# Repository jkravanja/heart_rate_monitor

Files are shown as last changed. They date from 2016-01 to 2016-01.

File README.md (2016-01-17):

# heart_rate_monitor
Heart rate monitor designed in KiCad, using Nordic Semiconductor NRF51822 bluetooth module and TI AFE4400 heart rate module.

The repository contains a KiCad design of a 5x5 cm heart rate monitor breakout board. Some libraries were borrowed from Guan Yang's github projects (https://github.com/guanix/boards). Also, some design aspects of the circuit were inspired by HackManhattan Nordic nrf51822 beakout board (http://dangerousprototypes.com/2013/05/19/hackmanhattans-nordic-nrf51822-breakout-board/)

[Schematics](https://github.com/jkravanja/heart_rate_monitor/blob/master/hr.pdf)

In addition to AFE440 for heart rate measurements and NRF51822 for BLE communications, the circuit also contains a [Freescale MMA8452 3-axis accelerometer](http://www.nxp.com/files/sensors/doc/data_sheet/MMA8452Q.pdf), CAT24M01 1Mb EEPROM and an additional heart rate circuit composed of just a few simple elements (see bottom center of the schematics). The circuit was inspired by [this article](http://www.biofotonika.lu.lv/fileadmin/user_upload/lu_portal/projekti/biofotonika/Publikacijas/A4/SPIE/22.Kviesis-A_photoplethysmography_device_for_multipurpose_bloo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) and presents a cheaper and simpler option to AFE4400.

Image of manufactured PCB

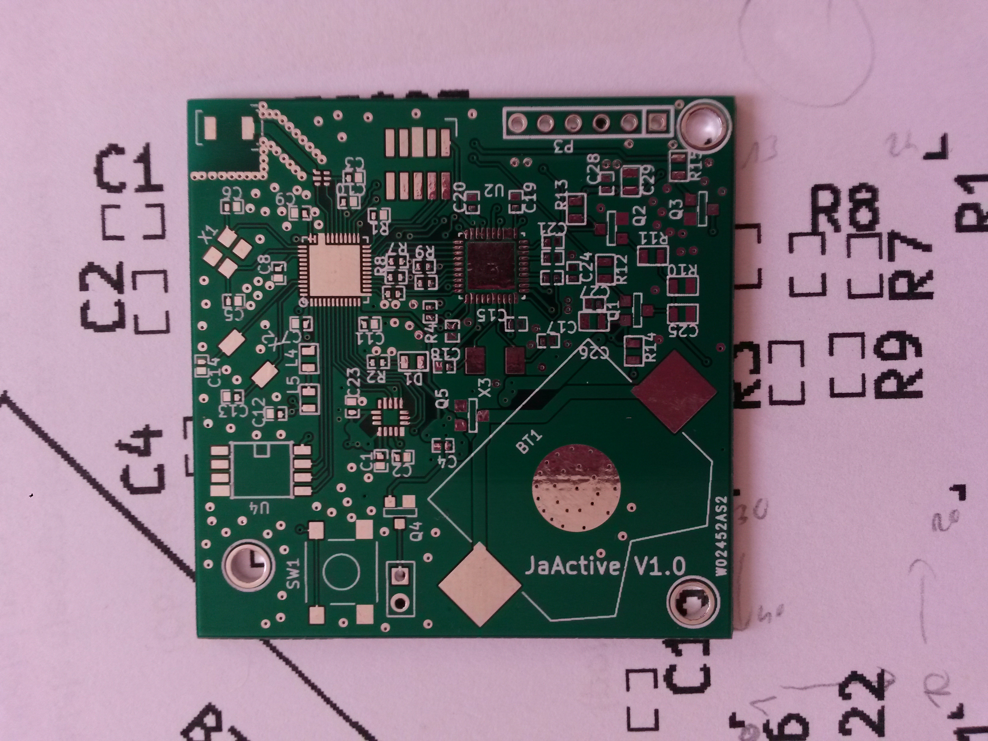
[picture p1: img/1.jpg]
Image of manufactured PCB


Components were soldered with reflow technique. Some joints had to be manually corrected using soldering iron

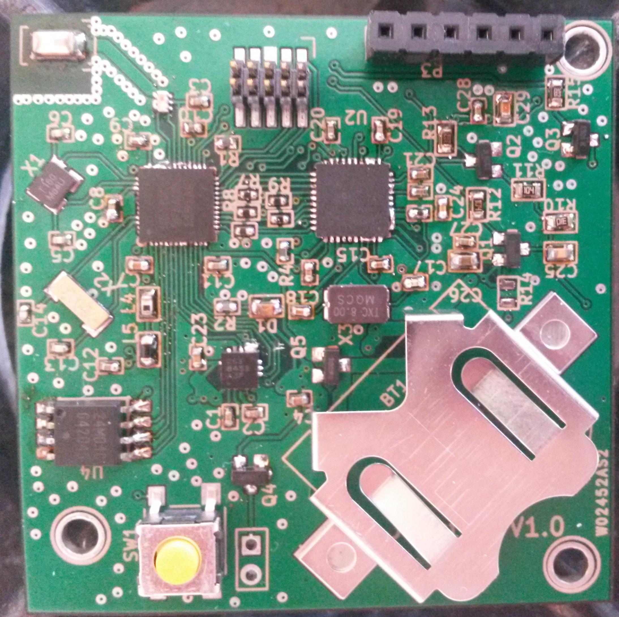
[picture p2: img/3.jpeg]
Added battery holder and connectors


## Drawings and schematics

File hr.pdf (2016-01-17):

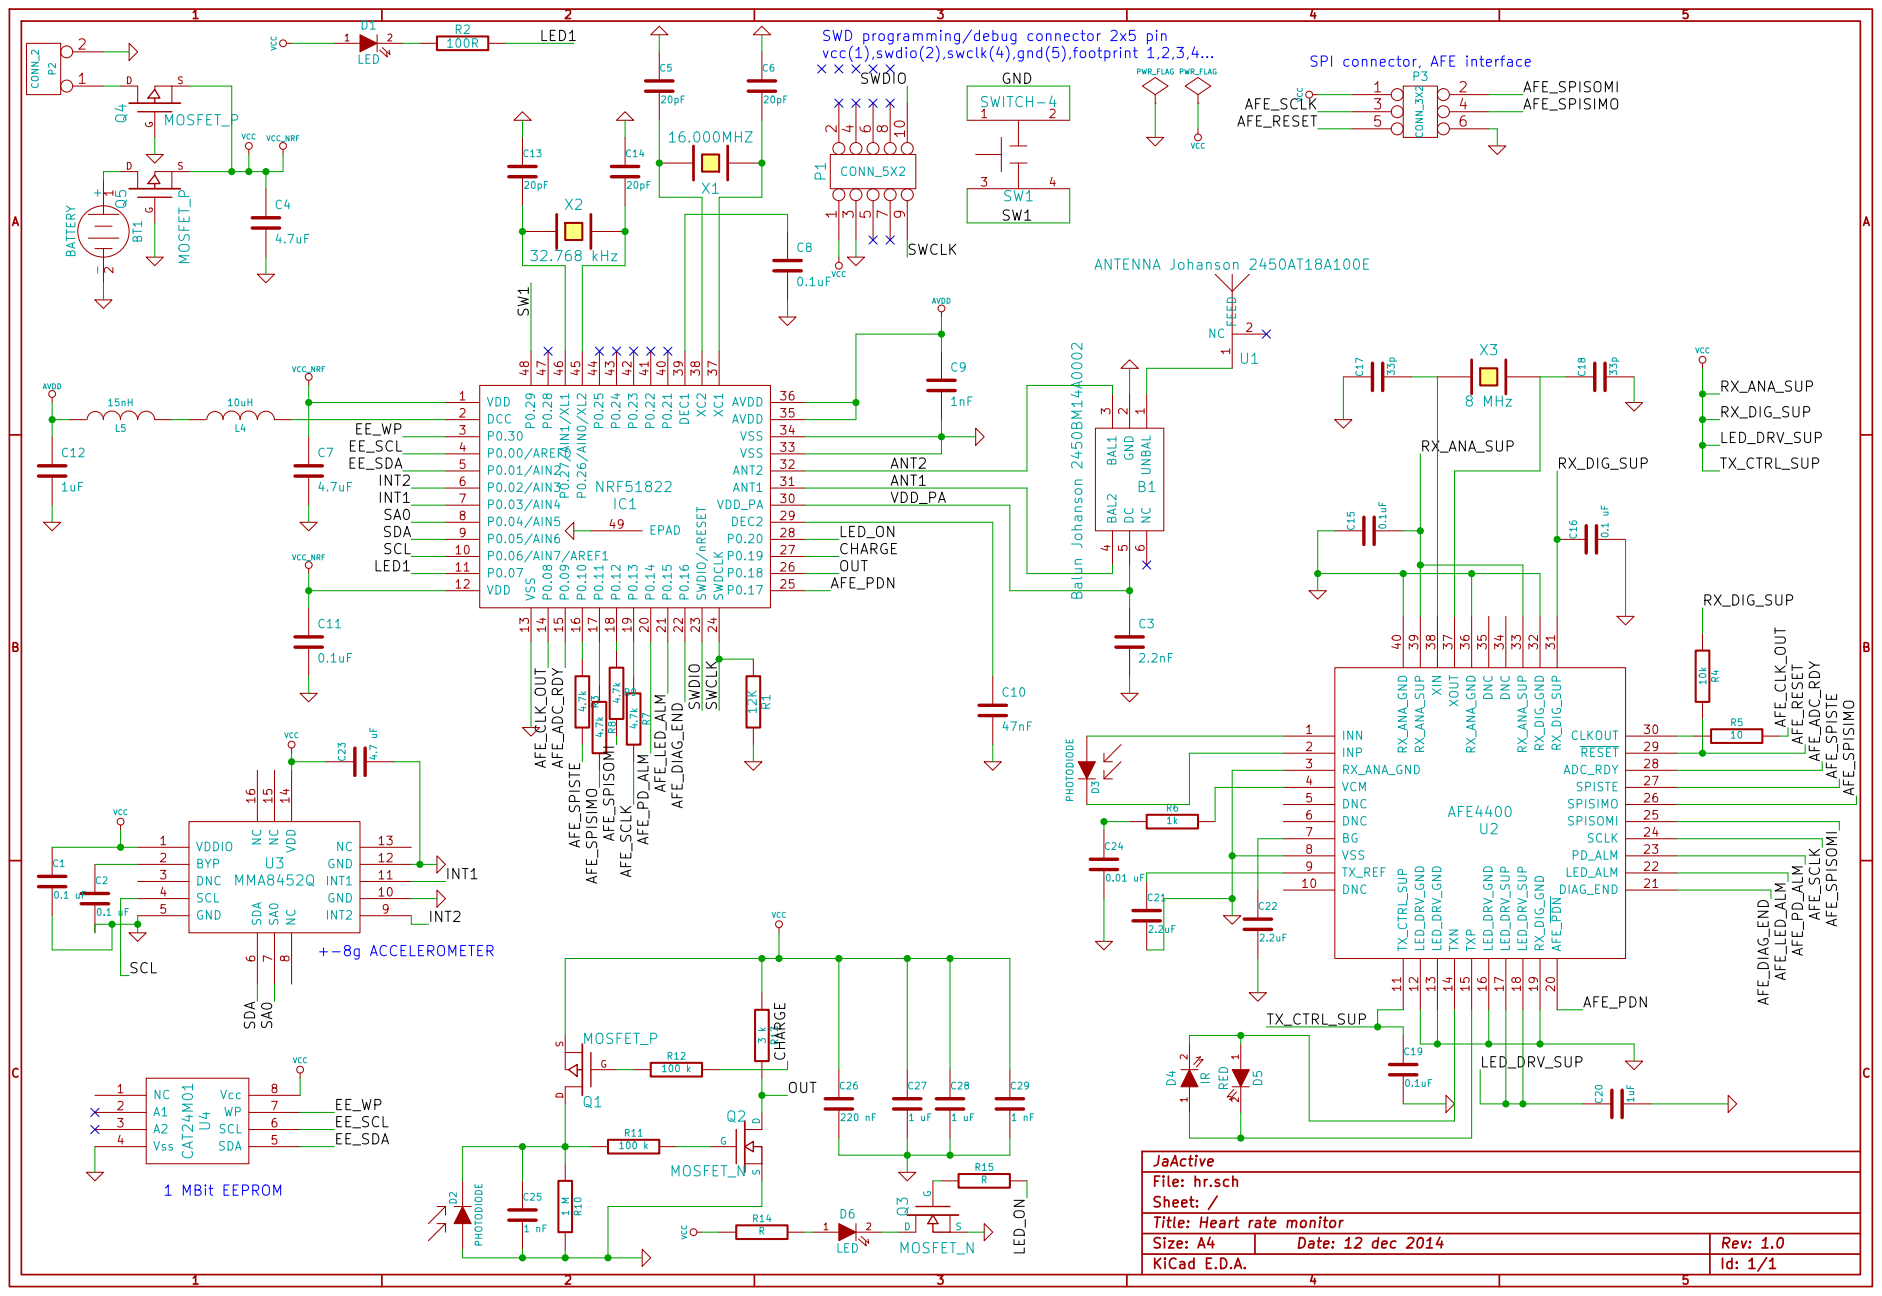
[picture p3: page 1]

SWD programming/debug connector 2x5 pin
vcc(1),swdio(2),swclk(4),gnd(5),footprint 1,2,3,4...

SPI connector, AFE interface

Id: 1/1 Title: Heart rate monitor File: hr.sch Sheet: / JaActive

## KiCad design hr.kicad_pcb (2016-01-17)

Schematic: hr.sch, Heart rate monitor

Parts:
B1: Balun Johanson 2450BM14A0002
BT1: BATTERY
C1, C2, C16: 0.1 uF
C3: 2.2nF
C4, C7: 4.7uF
C5, C6, C13, C14: 20pF
C8, C11: 0.1uF
C9: 1nF
C10: 47nF
C12: 1uF
C15, C19: 0.1uF
C17, C18: 33p
C20: 1uF
C21, C22: 2.2uF
C23: 4.7 uF
C24: 0.01 uF
C25, C29: 1 nF
C26: 220 nF
C27, C28: 1 uF
D1: LED
D2, D3: PHOTODIODE
D4: IR
D5: RED
D6: LED
IC1: NRF51822
L4: 10uH
L5: 15nH
P1: CONN_5X2
P2: CONN_2
P3: CONN_3X2
Q1, Q4, Q5: MOSFET_P
Q2, Q3: MOSFET_N
R1: 12K
R2: 100R
R3, R7, R8, R9: 4.7k
R4: 10k
R5: 10
R6: 1k
R10: 1 M
R11, R12: 100 k
R13: 3 k
R14, R15: R
SW1: SWITCH-4
U1: ANTENNA Johanson 2450AT18A100E
U2: AFE4400
U3: MMA8452Q
U4: CAT24M01
X1: 16.000MHZ
X2: 32.768 kHz
X3: 8 MHz

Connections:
/AFE_ADC_RDY: IC1.15 (P0.09), U2.28 (ADC_RDY)
/AFE_CLK_OUT: IC1.14 (P0.08), R5.2
/AFE_DIAG_END: IC1.22 (P0.16), U2.21 (DIAG_END)
/AFE_LED_ALM: IC1.21 (P0.15), U2.22 (LED_ALM)
/AFE_PDN: IC1.25 (P0.17), U2.20 (AFE_~PDN)
/AFE_PD_ALM: IC1.20 (P0.14), U2.23 (PD_ALM)
/AFE_RESET: P3.5, R4.2, U2.29 (~RESET)
/AFE_SCLK: P3.3, R7.2, U2.24 (SCLK)
/AFE_SPISIMO: P3.4, R8.2, U2.26 (SPISIMO)
/AFE_SPISOMI: P3.2, R9.2, U2.25 (SPISOMI)
/AFE_SPISTE: R3.2, U2.27 (SPISTE)
/ANT1: B1.4 (BAL2), IC1.31 (ANT1)
/ANT2: B1.3 (BAL1), IC1.32 (ANT2)
/CHARGE: IC1.27 (P0.19), R12.2
/EE_SCL: IC1.4 (P0.00/AREF0), U4.6 (SCL)
/EE_SDA: IC1.5 (P0.01/AIN2), U4.5 (SDA)
/EE_WP: IC1.3 (P0.30), U4.7 (WP)
/INT1: IC1.6 (P0.02/AIN3), U3.11 (INT1)
/INT2: IC1.7 (P0.03/AIN4), U3.9 (INT2)
/LED1: IC1.11 (P0.07), R2.2
/LED_ON: IC1.28 (P0.20), R15.2
/OUT: IC1.26 (P0.18), Q2.D, R13.2
/SA0: IC1.8 (P0.04/AIN5), U3.7 (SA0)
/SCL: IC1.10 (P0.06/AIN7/AREF1), U3.4 (SCL)
/SDA: IC1.9 (P0.05/AIN6), U3.6 (SDA)
/SW1: IC1.48 (P0.29), SW1.3, SW1.4
/SWCLK: IC1.24 (SWDCLK), P1.9, R1.1
/SWDIO: IC1.23 (SWDIO/nRESET), P1.10
/VDD_PA: B1.5 (DC), C3.1, IC1.30 (VDD_PA)
AVDD: C9.1, C12.1, IC1.35 (AVDD), IC1.36 (AVDD), L5.1
GND: B1.2 (GND), BT1.2 (-), C1.2, C2.2, C3.2, C4.2, C5.1, C6.1, C7.2, C8.2, C9.2, C10.2, C11.2, C12.2, C13.1, C14.1, C15.1, C16.2, C17.1, C18.2, C19.2, C20.2, C21.2, C22.2, C23.2, C24.2, C25.2, C26.2, C27.2, C28.2, C29.2, D2.1 (A), IC1.13 (VSS), IC1.33 (VSS), IC1.34 (VSS), IC1.49 (EPAD), P1.3, P2.2 (PM), P3.6, Q2.S, Q3.S, Q4.G, Q5.G, R1.2, R10.2, SW1.1, SW1.2, U2.3 (RX_ANA_GND), U2.8 (VSS), U2.12 (LED_DRV_GND), U2.13 (LED_DRV_GND), U2.16 (LED_DRV_GND), U2.19 (RX_DIG_GND), U2.32 (RX_DIG_GND), U2.36 (RX_ANA_GND), U2.40 (RX_ANA_GND), U2.41 (GND), U3.5 (GND), U3.10 (GND), U3.12 (GND), U4.4 (Vss)
unnamed: C17.2, U2.38 (XIN), X3.1
unnamed: C18.1, U2.37 (XOUT), X3.2
unnamed: C8.1, IC1.39 (DEC1)
unnamed: D1.2 (K), R2.1
unnamed: B1.1 (UNBAL), U1.1 (FEED)
unnamed: C10.1, IC1.29 (DEC2)
unnamed: D4.1 (A), D5.2 (K), U2.15 (TXP)
unnamed: D4.2 (K), D5.1 (A), U2.14 (TXN)
unnamed: D3.2 (K), U2.2 (INP)
unnamed: C22.1, U2.7 (BG)
unnamed: Q2.G, R11.2
unnamed: R5.1, U2.30 (CLKOUT)
unnamed: D6.1 (A), R14.2
unnamed: D6.2 (K), Q3.D
unnamed: Q3.G, R15.1
unnamed: Q1.G, R12.1
unnamed: IC1.16 (P0.10), R3.1
unnamed: IC1.17 (P0.11), R8.1
unnamed: IC1.18 (P0.12), R9.1
unnamed: IC1.19 (P0.13), R7.1
unnamed: BT1.1 (+), Q5.D
unnamed: P2.1, Q4.D
unnamed: C21.1, U2.9 (TX_REF)
unnamed: C24.1, R6.1
unnamed: IC1.2 (DCC), L4.2
unnamed: L4.1, L5.2
unnamed: R6.2, U2.4 (VCM)
unnamed: D3.1 (A), U2.1 (INN)
unnamed: C25.1, D2.2 (K), Q1.D, R10.1, R11.1
unnamed: C2.1, U3.2 (BYP)
unnamed: C6.2, IC1.37 (XC1), X1.1
unnamed: C5.2, IC1.38 (XC2), X1.2
unnamed: C13.2, IC1.46 (P0.27/AIN1/XL1), X2.1
unnamed: C14.2, IC1.45 (P0.26/AIN0/XL2), X2.2

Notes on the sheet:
1 MBit EEPROM
+-8g ACCELEROMETER
SWD programming/debug connector 2x5 pin
SPI connector, AFE interface
vcc(1),swdio(2),swclk(4),gnd(5),footprint 1,2,3,4...

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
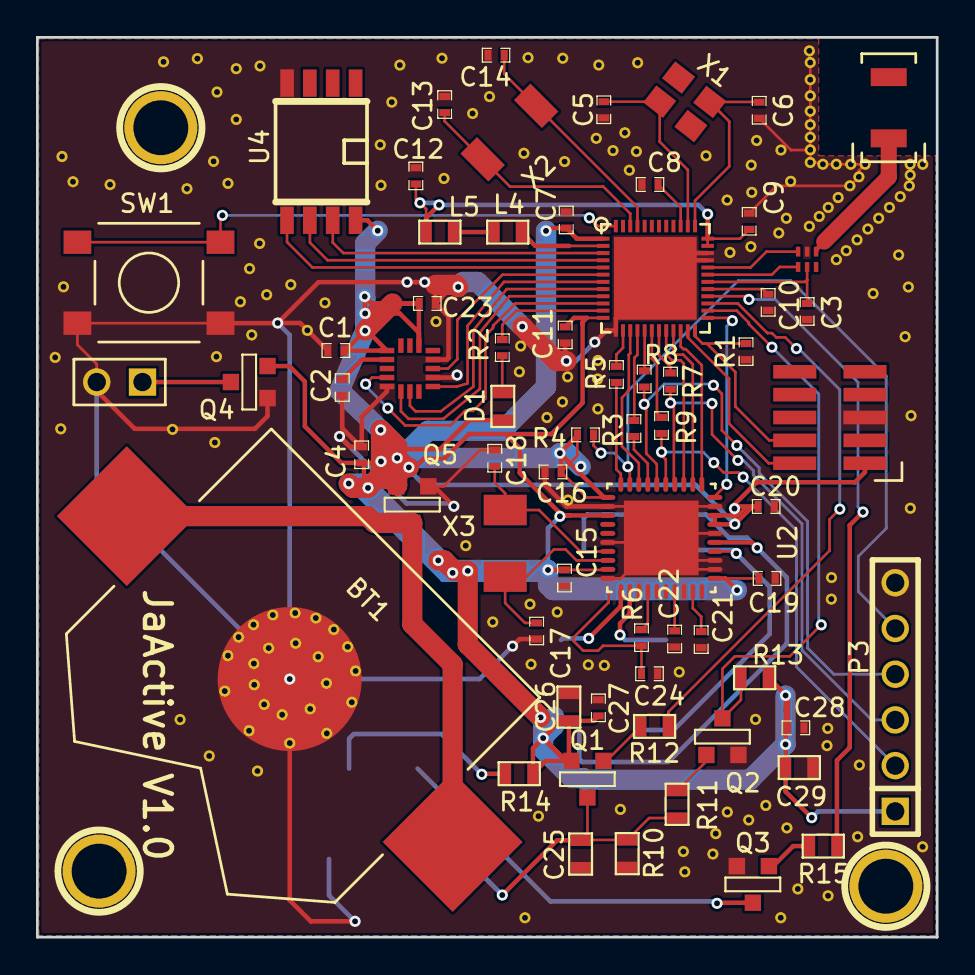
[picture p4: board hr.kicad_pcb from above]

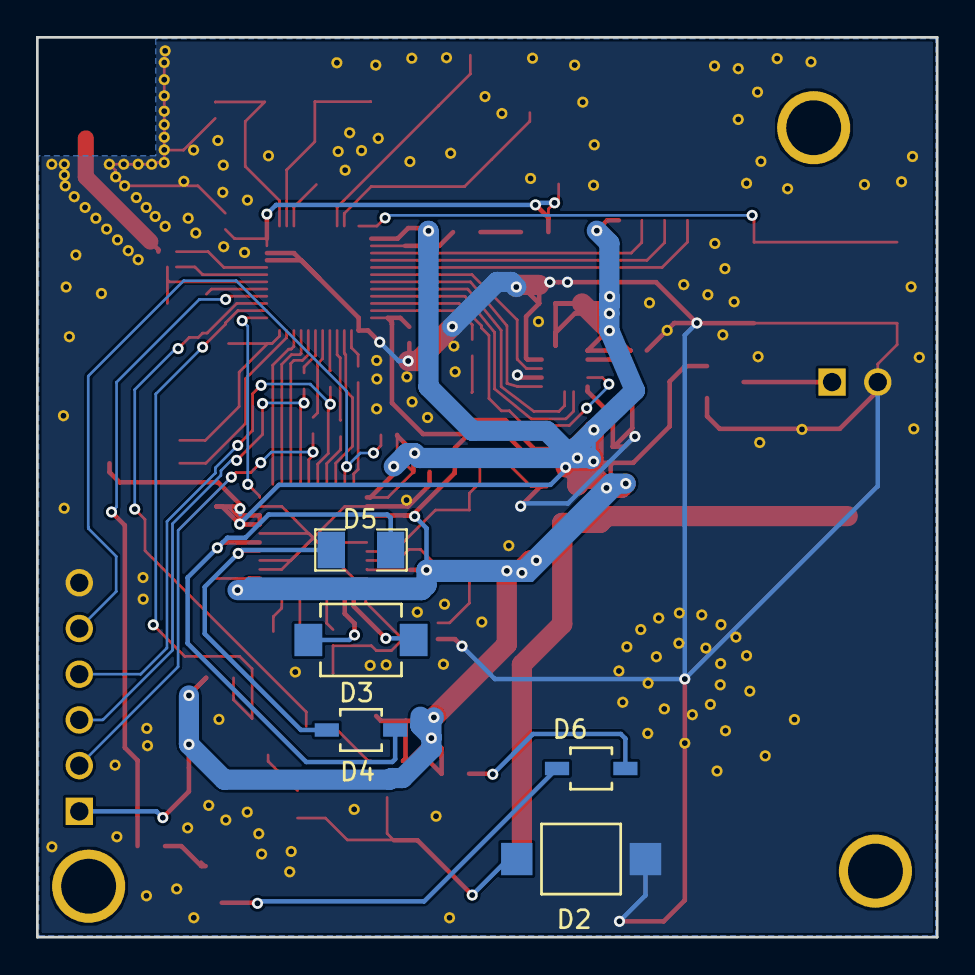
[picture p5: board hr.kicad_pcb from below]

Board: 2 copper layers, 50.0 x 50.0 mm, 74 parts (5 on the bottom side), 66 nets.

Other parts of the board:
1PIN, 1PIN#2, 1PIN#3: P***; 1pin

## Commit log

2016-01-17 Initial commit.
    [hr-B_Cu.gbl, hr-B_Mask.gbs, hr-B_SilkS.gbo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]
2016-01-17 Delete _autosave-.kicad_pcb
    remove _autosave
